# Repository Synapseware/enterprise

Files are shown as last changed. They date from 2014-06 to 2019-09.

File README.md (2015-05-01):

Enterprise
==========
The Enterprise is a project which adds sound and light effects to a small plastic model USS Enterprise from the original Star Trek TV show.  There are various pieces and parts to make this massively over complicated system work.  For me, this project is about learning better techniques for making circuit boards, programming embedded systems and generally wasting massive amounts of time.

# Project Structure
## /board
This is where the Eagle CAD files reside.  You should use Eagle v7 (or greater) to view/edit.

## /core
The heart of the system, driven by an Atmel ATMega328p micro controller clockec at 20MHz.  This is a hand built system and *does not run any Arduino firmware.*  The core is responsible for playing sound effects and coordinating light effects throughout the ship.

## /eeprom-test
A diagnostic firmware image for tracking down problems with the C++ conversion, hardware issues, etc, that are preventing the EEPROM chips from working correctly.

## /effects
The sound files used to generate the the EEPROM image file, and the latest binary EEPROM image file.  Plus lots of ther other sound effects.

## /entutil
Various programs written in C++ (tested only on Linux), mainly for converting 8bit 8KHz wave files to a standard EEPROM image file for uploading to the core.

## /lib
Shared code, drivers and other utilities extracte from the [libs](https://github.com/Synapseware/libs/libs.git) repository.

## /nacelle
A sub project within the main Enterprise project, the [Nacelle](https://github.com/Synapseware/enterprise/tree/master/nacelle) folder contains all the Atmel assembly language files for the nacelle lighting effects boards.

# Processing
## The core is responsible for:
* Sending new lighting effects to the Nacelle's for storage via EEPROM
* Sound?
* Some lighting effects
* USB interface

## Unsupported functionality:
* Processing battery level
* Uploading new firmware to subordinate processors

## Hardware System Composition
* Main CPU board
  * Main CPU
  * core lighting effects support
  * sound effects & speaker driver
* Power & USB board
  * USB to COM port
  * charging LiPo battery
  * 5V boost/regulator
* Nacelle boards (2 total)
  * nacelle lighting effects

The power & USB board provides communications for the system via a USB to virtual COM port driver chip, as well as a 5V boost/regulator for powering the CPU's.  The board has 6 outputs, 2 for serial RX & TX, USB power, 5V boost, raw battery line and ground.  The connector is meant to mate to the main board so that the main board can receive power and communications lines without the risk of a highly complicated system board.

The main CPU board has a single ATMega328P micro-controller (uC) which drives the sound effects, core lighting effects and is able to communicate with the nacelle driver boards via I2C.

### Board Details

	Power Board pinout (facing up, pins down, L-R)
	1 - RX
	2 - TX
	3 - VBUS
	4 - VBATT
	5 - VBOOST (5V)
	6 - GND

	Nacelle Board pinout (facing up, pins down, L-R)
	1 - MOSI/SDA
	2 - MISO
	3 - SCK/SCL
	4 - Pwr
	5 - GND
	6 = Reset

## Diagnostics
There are 4 LEDs on the main board located near the programming header.  In order from board edge in:
* Heartbeat
* Sound play back
* Serial transfers
* I2C transfers

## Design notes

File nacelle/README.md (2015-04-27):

Nacelle
=======
Nacelle lighting effects for the Enterprise project.

Platform:	ATTiny2313
Source:		AVR assembly

***Built using AVRA!***

## Theory
The Nacelle "driver" is an ATTiny2313 clocked at 20MHz.  It is configured to push data over a serial interface to a pair of chained ST16CP05 LED driver chips.  This was chosen over the original Charlie-plexed design for wiring simplicity.

The Nacelle driver board is designed to communicate with the Enterprise core board via an I2C interface.  The core will send effects commands to the driver boards at various times to change the speed, direction, brightness, etc, of the nacelle animations.

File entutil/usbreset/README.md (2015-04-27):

USB Reset
=========

1) Compile the program:
    
    $ make

2) Get the Bus and Device ID of the USB device you want to reset:

    $ lsusb  
*Output:*
    Bus 002 Device 003: ID 0fe9:9010 DVICO  

3) Make our compiled program executable:

    $ chmod +x usbreset

4) Execute the program with sudo privilege
    - make necessary substitution for <Bus> and <Device> ids as found by running the lsusb command:

    $ sudo ./usbreset /dev/bus/usb/002/003

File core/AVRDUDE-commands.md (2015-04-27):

AVRDUDE commands
================
For interacting with the Enterprise main board.

# Upload & Fuses

### programming
	avrdude -c usbtiny -p m328p -B 1 -U flash:w:.\release\enterprise.hex

### reading fuses
	avrdude -c usbtiny -p m328p -B 8 -U hfuse:r:.\high.txt:h -U lfuse:r:.\low.txt:h -U efuse:r:.\ext.txt:h

### writing fuses
*(external crystal)*
	avrdude -c usbtiny -p m328p -B 8 -U lfuse:w:0xff:m -U hfuse:w:0xdf:m -U efuse:w:0xff:m

*(internal 8mHz r/c)*
	avrdude -c usbtiny -p m328p -B 8 -U lfuse:w:0xe2:m -U hfuse:w:0xdf:m -U efuse:w:0xff:m

## Build tool test...
echo avrdude -c usbtiny -p $(avrdevice) -B 8 -U flash:w:"$(OutputDirectory)\$(MSBuildProjectName).hex" > upload.bat

avrdude -c usbtiny -p usb162 -U hfuse:r:.\high.txt:h -U lfuse:r:.\low.txt:h -U efuse:r:.\ext.txt:h
avrdude -c usbtiny -p usb162 -U lfuse:w:0xde:m -U hfuse:w:0xd9:m -U efuse:w:0xf7:m
avrdude -c usbtiny -p usb162 -U lfuse:w:0xde:m -U hfuse:w:0xd1:m -U efuse:w:0xf4:m

avrdude -c usbtiny -p usb162 -U lfuse:w:0xff:m
avrdude -c usbtiny -p usb162 -U hfuse:w:0xd1:m
avrdude -c usbtiny -p usb162 -U efuse:w:0xf4:m

## i2c/twi execution notes:
	@ 400kHz (1/4x10+6 = 2.5x10-6), it takes 2.5uS to transfer a single bit. 2.5x10-6 x 8 = 20uS per byte.  The AVR core @ 20MHz can theoretically execute 2x10+8/second or 1 instruction every 50x10-12 (50nS) seconds.  20uS is 200 times slower, so 200 instructions for every i2c byte transfer.
    It's well worth it to have the I2C interface be interrupt driven.

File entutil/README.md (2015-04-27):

Enterprise Utility Programs
===========================

## stitch
Stitch's together a series of raw audio files and generates the proper output bin file.  Stitch should operate on files that were created by the 'scvt' utility.

### Help info
	stitch - EEPROM sound effects utility builder for the Enterprise
	   combines a set of wav files into a single output file suitable for programming to the EEPROM on the Enterprise board.

	stitch -o {outputfile} -p {pagesize} {input file 1...n}
	   -o  Output file name.
	   -p  Page size.  This must reflect the page size of the target hardware.  256 bytes is the required size for the AT24C1024 chip.
	   {input files}  Give a list of pre-processed WAV files.  Preprocessing is done by the scvt (Sound Convert) utility.

## scvt
Converts a single .wav file (RIFF WAVE format) file to the raw Enterprise EEPROM format, which is simply the audio data from the input wave file.  Files must be 8bit, mono, below 22kHz sample rate.  Ideally files will be 8kHz.  The extracted audio is always saved to a new file with an extension of "snd".

### Examples

	scvt spock-bridge.wav

Takes the "spock-bridge.wav" file, verifies that it contains only 8 bit mono sound data with an 8kHz sampling rate then extracts just the audio chunk and saves it to a new file named "spock-bridge.snd" file in the same directory as the input file.  Any existing file will be over written.

### Help info

	scvt {input file}
	   Converts a standard wave file to the intermediary Enterprise format.

## upload
Uploads an effects EEPROM image to the Enterprise.  Default speed is 57600.

### Examples:

	upload -p /dev/ttyACM0 -i {image-file}
	upload -b 9600 -p /dev/ttyACM0 -i {image-file}

### Saving settings:
To save the current port and BAUD rate, specify the -s flag.

### Help info
	upload -i {filename} -p {serial port} -b {baud rate} -s
	Uploads an EEPROM effects file to the Enterprise.
	  -i  The EEPROM image file to upload to the Enterprise.
	  -b  Specify the baud rate to use.  Must be a standard value (e.g. 9600, 57600, etc).
	  -p  Specify the serial port to use.
	         List serial ports with 'll /dev/tty*' at the command prompt.
	  -s  Save the given port and baud rate as the new defaults.
	         Note: settings are saved in the .upload-settings file in the current directory.

## hdrinfo
View information about an EEPROM image by examining the first 256 bytes of the file.

	hdrinfo {image-file}

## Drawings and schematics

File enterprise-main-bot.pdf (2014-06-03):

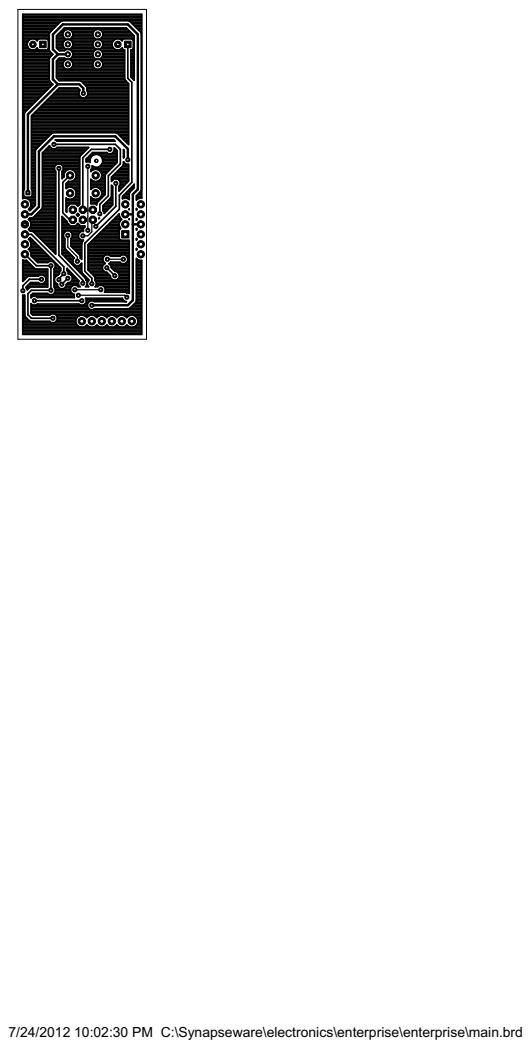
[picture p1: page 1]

7/24/2012 10:02:30 PM C:\Synapseware\electronics\enterprise\enterprise\main.brd

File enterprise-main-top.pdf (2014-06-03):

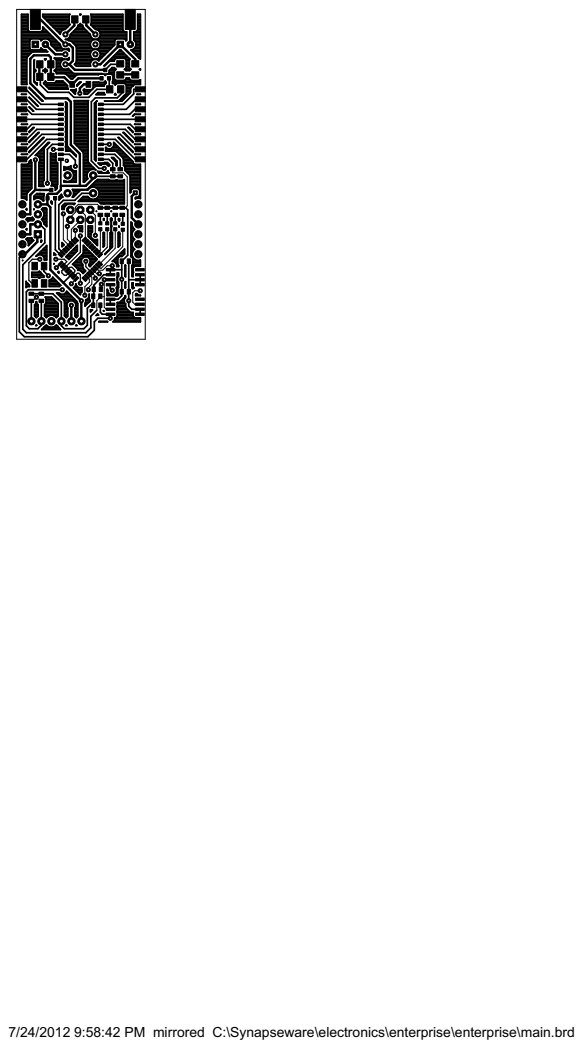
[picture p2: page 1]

7/24/2012 9:58:42 PM mirrored C:\Synapseware\electronics\enterprise\enterprise\main.brd

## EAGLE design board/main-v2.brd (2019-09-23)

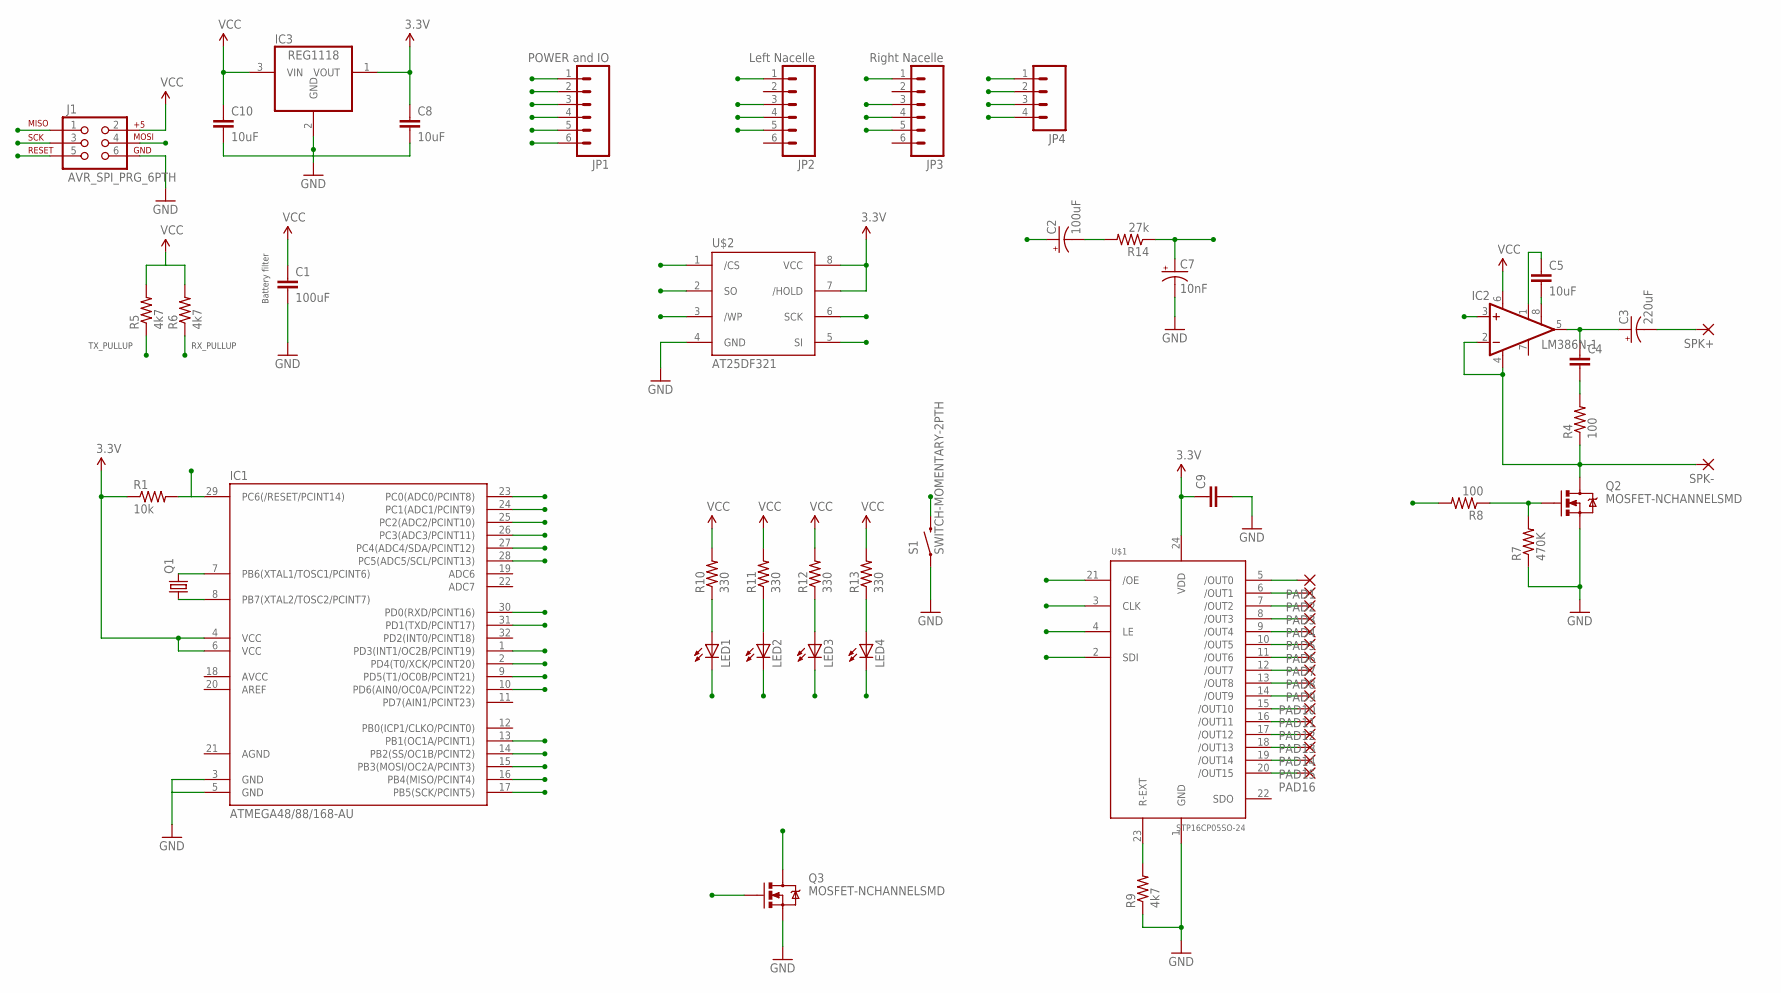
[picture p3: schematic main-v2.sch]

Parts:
C1: 100uF; CTZ3
C2: 100uF; CPOL-RADIAL-10UF-25V
C3: 220uF; CPOL-RADIAL-10UF-25V
C4: CAP1206; 1206
C5: 10uF; 1206
C7: 10nF; CPOL-RADIAL-10UF-25V
C8, C10: 10uF; CTZ3
C9: CAP0805; 0805
IC1: ATMEGA48/88/168-AU; TQFP32-08
IC2: LM386N-1; DIL08
IC3: REG1118; SOT223
J1: AVR_SPI_PRG_6PTH; 2X3
JP1: POWER and IO; 1X06
JP2: Left Nacelle; 1X06
JP3: Right Nacelle; 1X06
JP4: M04PTH; 1X04
LED1, LED2, LED3, LED4: LED0603; LED-0603
PAD1, PAD2, PAD3, PAD4, PAD5, PAD6, PAD7, PAD8, PAD9, PAD10, PAD11, PAD12, PAD13, PAD14, PAD15, PAD16: SMD2; SMD1,27-2,54
Q1: CRYSTALCTS406; CTS406
Q2, Q3: MOSFET-NCHANNELSMD; SOT23-3
R1: 10k; 0805
R4, R8: 100; 1206
R5, R6, R9: 4k7; 0805
R7: 470K; 1206
R10, R11, R12, R13: 330; 0805
R14: 27k; 1206
S1: SWITCH-MOMENTARY-2PTH; TACTILE-PTH
SPK+: SMD5; SMD2,54-5,08
SPK-: SMD5; SMD2,54-5,08
U$1: STP16CP05SO-24; SO-24
U$2: AT25DF321; WSOIC-8

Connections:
3.3V: C8.+ (1), C9.1, IC1.4 (VCC), IC1.6 (VCC), IC3.1 (VOUT), R1.1, U$1.24 (VDD), U$2.7 (/HOLD), U$2.8 (VCC)
/OE: IC1.13 (PB1(OC1A/PCINT1)), U$1.21 (/OE)
/SS: IC1.14 (PB2(SS/OC1B/PCINT2)), U$1.4 (LE), U$2.1 (/CS)
AGND: IC1.21 (AGND)
AUDIO_PWR: IC1.2 (PD4(T0/XCK/PCINT20)), R8.2
FILTERED_PWM: C7.1 (+), IC2.3 (+IN), R14.1
GND: C1.- (2), C7.2 (-), C8.- (2), C9.2, C10.- (2), IC1.3 (GND), IC1.5 (GND), IC3.2 (GND), J1.6, JP1.6, JP4.4, Q2.2 (S), Q3.2 (S), R7.1, R9.1, S1.1, U$1.1 (GND), U$2.4 (GND)
LED1: IC1.23 (PC0(ADC0/PCINT8)), LED1.C
LED2: IC1.24 (PC1(ADC1/PCINT9)), LED2.C
LED3: IC1.25 (PC2(ADC2/PCINT10)), LED3.C
LED4: IC1.26 (PC3(ADC3/PCINT11)), LED4.C
MISO: IC1.16 (PB4(MISO/PCINT4)), J1.1, U$2.2 (SO)
MOSI: IC1.15 (PB3(MOSI/OC2A/PCINT3)), J1.4, U$1.2 (SDI), U$2.5 (SI)
unnamed: IC1.8 (PB7(XTAL2/TOSC2/PCINT7)), Q1.1
unnamed: IC1.7 (PB6(XTAL1/TOSC1/PCINT6)), Q1.3 (2)
unnamed: C3.1 (+), C4.1, IC2.5 (OUT)
unnamed: C5.1, IC2.1 (GAIN)
unnamed: C4.2, R4.2
unnamed: C5.2, IC2.8 (GAIN)
unnamed: Q2.1 (G), R7.2, R8.1
unnamed: IC2.2 (-IN), IC2.4 (GND), Q2.3 (D), R4.1, SPK-.1
unnamed: LED1.A, R10.1
unnamed: LED2.A, R11.1
unnamed: R9.2, U$1.23 (R-EXT)
unnamed: LED3.A, R12.1
unnamed: LED4.A, R13.1
unnamed: PAD1.1, U$1.5 (/OUT0)
unnamed: PAD2.1, U$1.6 (/OUT1)
unnamed: PAD3.1, U$1.7 (/OUT2)
unnamed: PAD4.1, U$1.8 (/OUT3)
unnamed: PAD5.1, U$1.9 (/OUT4)
unnamed: PAD6.1, U$1.10 (/OUT5)
unnamed: PAD7.1, U$1.11 (/OUT6)
unnamed: PAD8.1, U$1.12 (/OUT7)
unnamed: PAD9.1, U$1.13 (/OUT8)
unnamed: PAD10.1, U$1.14 (/OUT9)
unnamed: PAD11.1, U$1.15 (/OUT10)
unnamed: PAD12.1, U$1.16 (/OUT11)
unnamed: PAD13.1, U$1.17 (/OUT12)
unnamed: PAD14.1, U$1.18 (/OUT13)
unnamed: PAD15.1, U$1.19 (/OUT14)
unnamed: PAD16.1, U$1.20 (/OUT15)
unnamed: C2.2 (-), R14.2
NCL_GND: JP2.5, JP3.5, Q3.3 (D)
NCL_PWR: IC1.9 (PD5(T1/OC0B/PCINT21)), Q3.1 (G)
PWM_AUDIO: C2.1 (+), IC1.1 (PD3(INT1/OC2B/PCINT19))
PWR_SW: IC1.10 (PD6(AIN0/OC0A/PCINT22)), S1.3 (2)
RESET: IC1.29 (PC6(/RESET/PCINT14)), J1.5, R1.2
RX: IC1.30 (PD0(RXD/PCINT16)), JP1.2, R6.1
SCK: IC1.17 (PB5(SCK/PCINT5)), J1.3, U$1.3 (CLK), U$2.6 (SCK)
SCL: IC1.28 (PC5(ADC5/SCL/PCINT13)), JP2.3, JP3.3, JP4.2
SDA: IC1.27 (PC4(ADC4/SDA/PCINT12)), JP2.1, JP3.1, JP4.1
SPK+: C3.2 (-), SPK+.1
TX: IC1.31 (PD1(TXD/PCINT17)), JP1.1, R5.1
VBATT: C1.+ (1), JP1.5, JP2.4, JP3.4, JP4.3
VBUS: JP1.3
VCC: JP1.4, R5.2, R6.2, R10.2, R11.2, R12.2, R13.2
VCC+5V: C10.+ (1), IC2.6 (VS), IC3.3 (VIN), J1.2

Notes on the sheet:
TX_PULLUP
RX_PULLUP
Battery filter

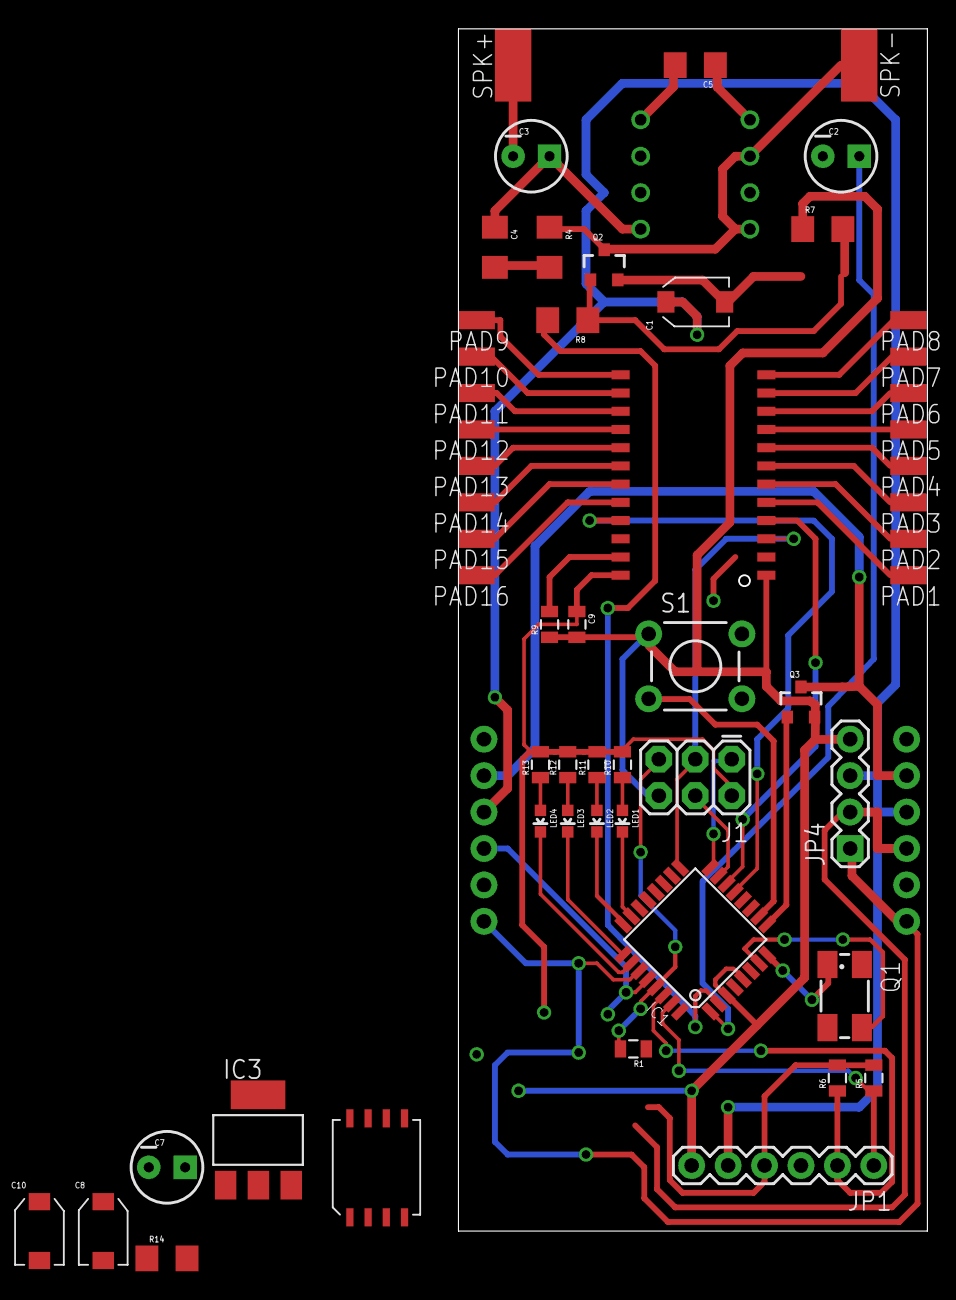
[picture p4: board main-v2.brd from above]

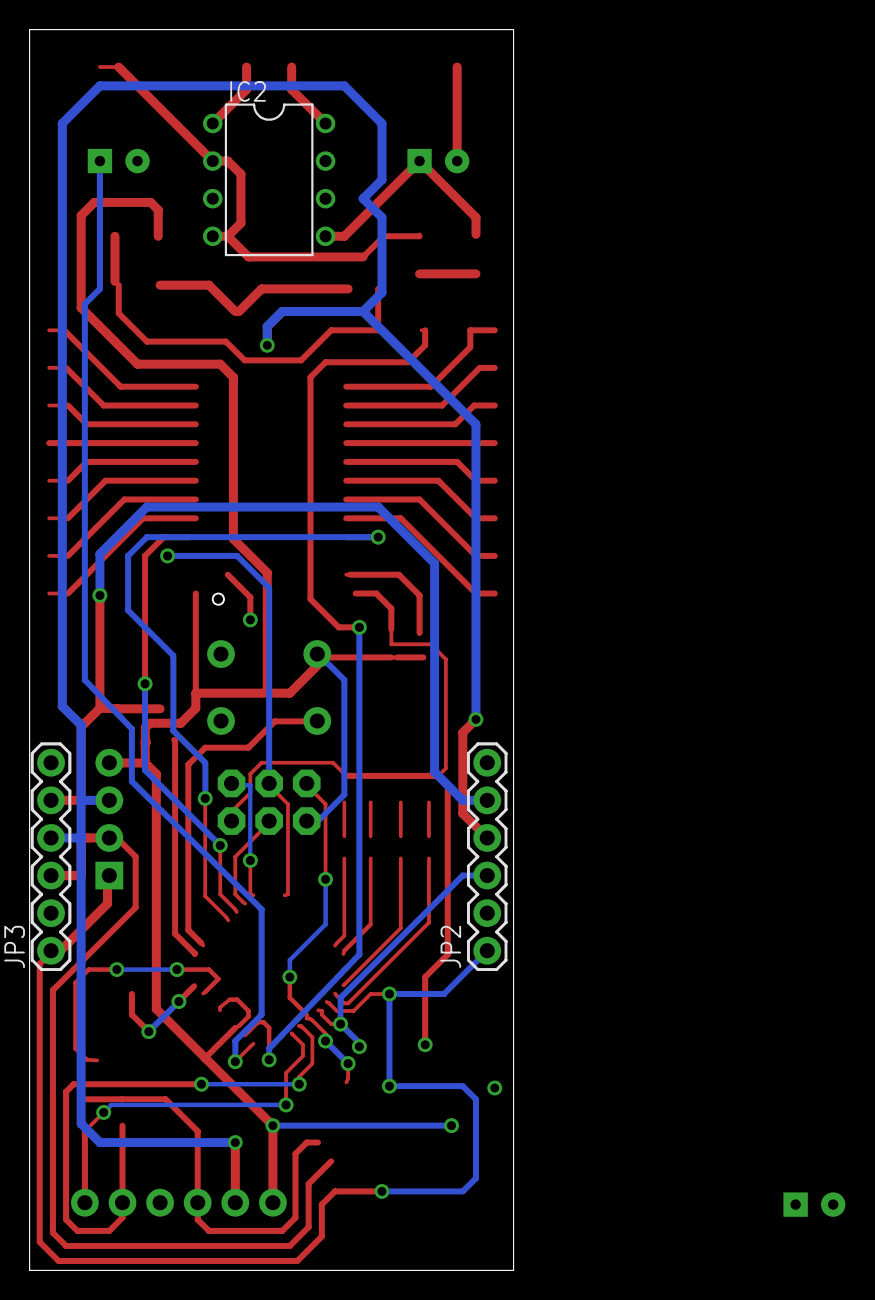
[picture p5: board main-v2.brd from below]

Board: 2 copper layers, 32.7 x 83.8 mm, 57 parts (3 on the bottom side), 56 nets.

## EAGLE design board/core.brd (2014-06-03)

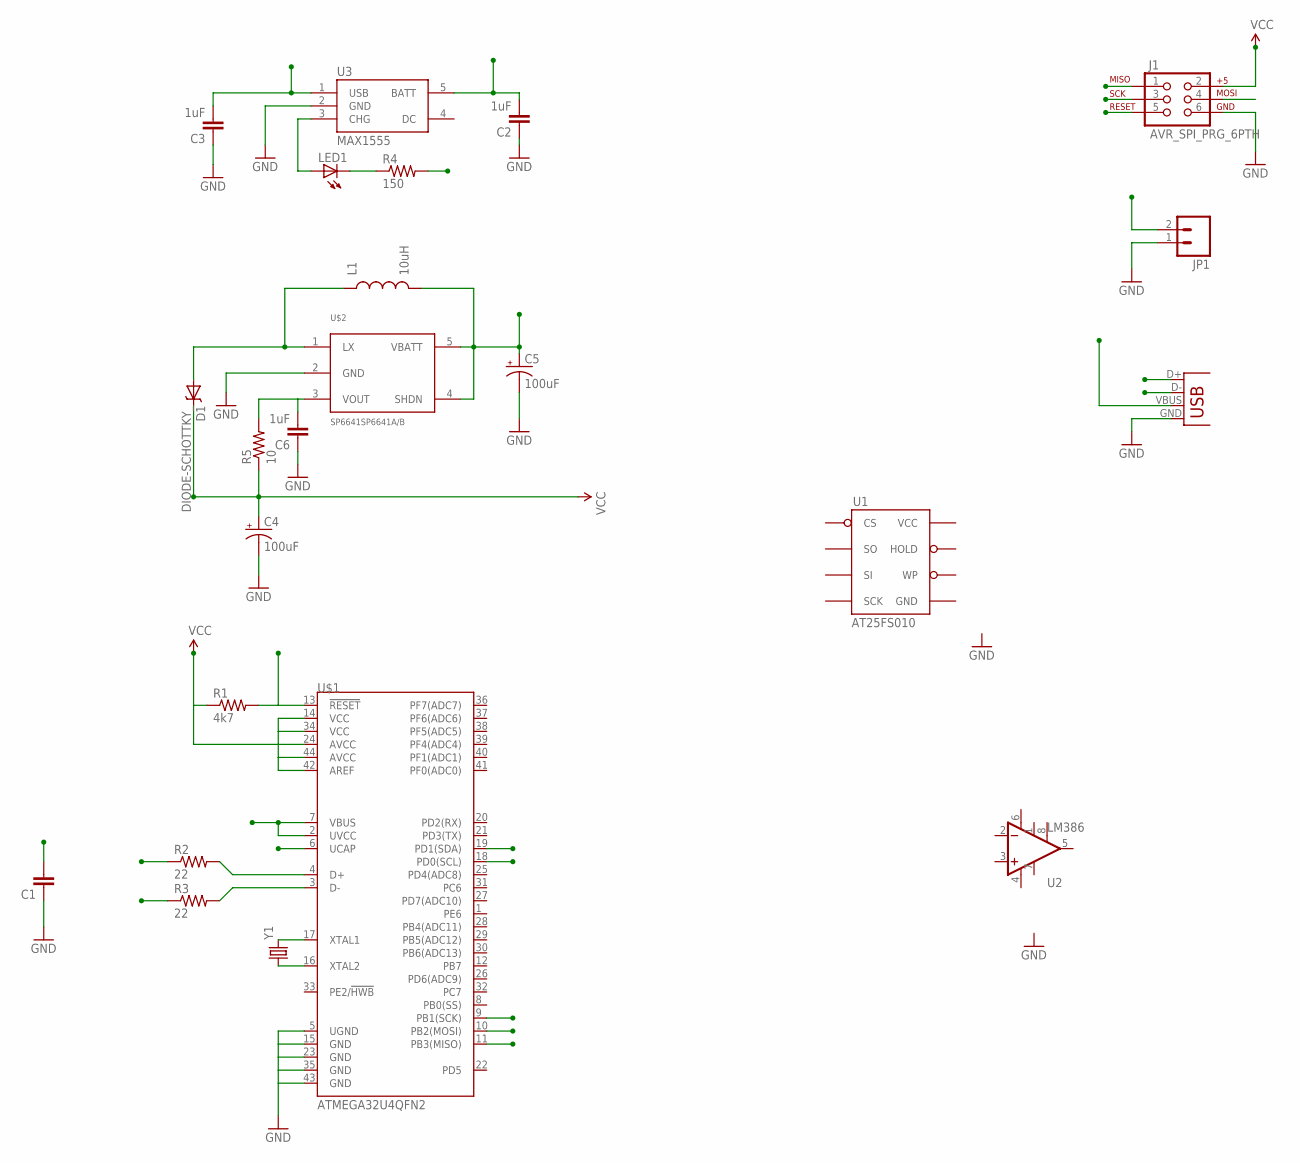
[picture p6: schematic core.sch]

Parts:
C1: CAP1206; 1206
C2, C3: 1uF; 1206
C4, C5: 100uF; PANASONIC_E
C6: 1uF; 0603-CAP
D1: DIODE-SCHOTTKY_; SMA-DIODE
J1: AVR_SPI_PRG_6PTH; 2X3
JP1: M02-JST-2MM-SMT; JST-2-SMD
L1: 10uH; CR75
LED1: LED0603; LED-0603
R1: 4k7; 0603-RES
R2, R3: 22; 0603-RES
R4: 150; 0603-RES
R5: 10; 0603-RES
U1: AT25FS010; SO08WIDE
U2: LM386; DIP08
U3: MAX1555; SOT23-5
U$1: ATMEGA32U4QFN2; QFN-44-NOPAD
U$2: SP6641SP6641A/B; SOT23-5
X1: USBSMD; USB-MINIB
Y1: CRYSTAL5X3; CRYSTAL-SMD-5X3

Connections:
/RESET: J1.5, R1.2, U$1.13 (!RESET)
GND: C1.1, C2.1, C3.1, C4.-, C5.-, C6.1, J1.6, JP1.1 (2), U3.2 (GND), U$1.5 (UGND), U$1.15 (GND), U$1.23 (GND), U$1.35 (GND), U$1.43 (GND), U$2.2 (GND), X1.GND
MISO: J1.1, U$1.11 (PB3(MISO))
MOSI: J1.4, U$1.10 (PB2(MOSI))
unnamed: R3.2, U$1.3 (D-)
unnamed: R2.2, U$1.4 (D+)
unnamed: LED1.A, U3.3 (CHG)
unnamed: LED1.C, R4.1
unnamed: D1.A, L1.P$1 (1), U$2.1 (LX)
unnamed: U$1.17 (XTAL1), Y1.3 (2)
unnamed: U$1.16 (XTAL2), Y1.1
unnamed: C6.2, R5.2, U$2.3 (VOUT)
SCK: J1.3, U$1.9 (PB1(SCK))
SCL: U$1.18 (PD0(SCL))
SDA: U$1.19 (PD1(SDA))
UCAP: C1.2, U$1.6 (UCAP)
USB_D+: R2.1, X1.D+
USB_D-: R3.1, X1.D-
V+: U2.6 (V+)
V-: U2.4 (V-)
VBATT: C2.2, C5.+, JP1.2 (1), L1.P$2 (2), U3.5 (BATT), U$2.4 (SHDN), U$2.5 (VBATT)
VBUS: C3.2, R4.2, U3.1 (USB), U$1.2 (UVCC), U$1.7 (VBUS), X1.VBUS
VCC: C4.+, D1.C, J1.2, R1.1, R5.1, U$1.14 (VCC), U$1.24 (AVCC), U$1.34 (VCC), U$1.42 (AREF), U$1.44 (AVCC)

Board: 2 copper layers, 23 parts (0 on the bottom side), 19 nets, no tracks yet.

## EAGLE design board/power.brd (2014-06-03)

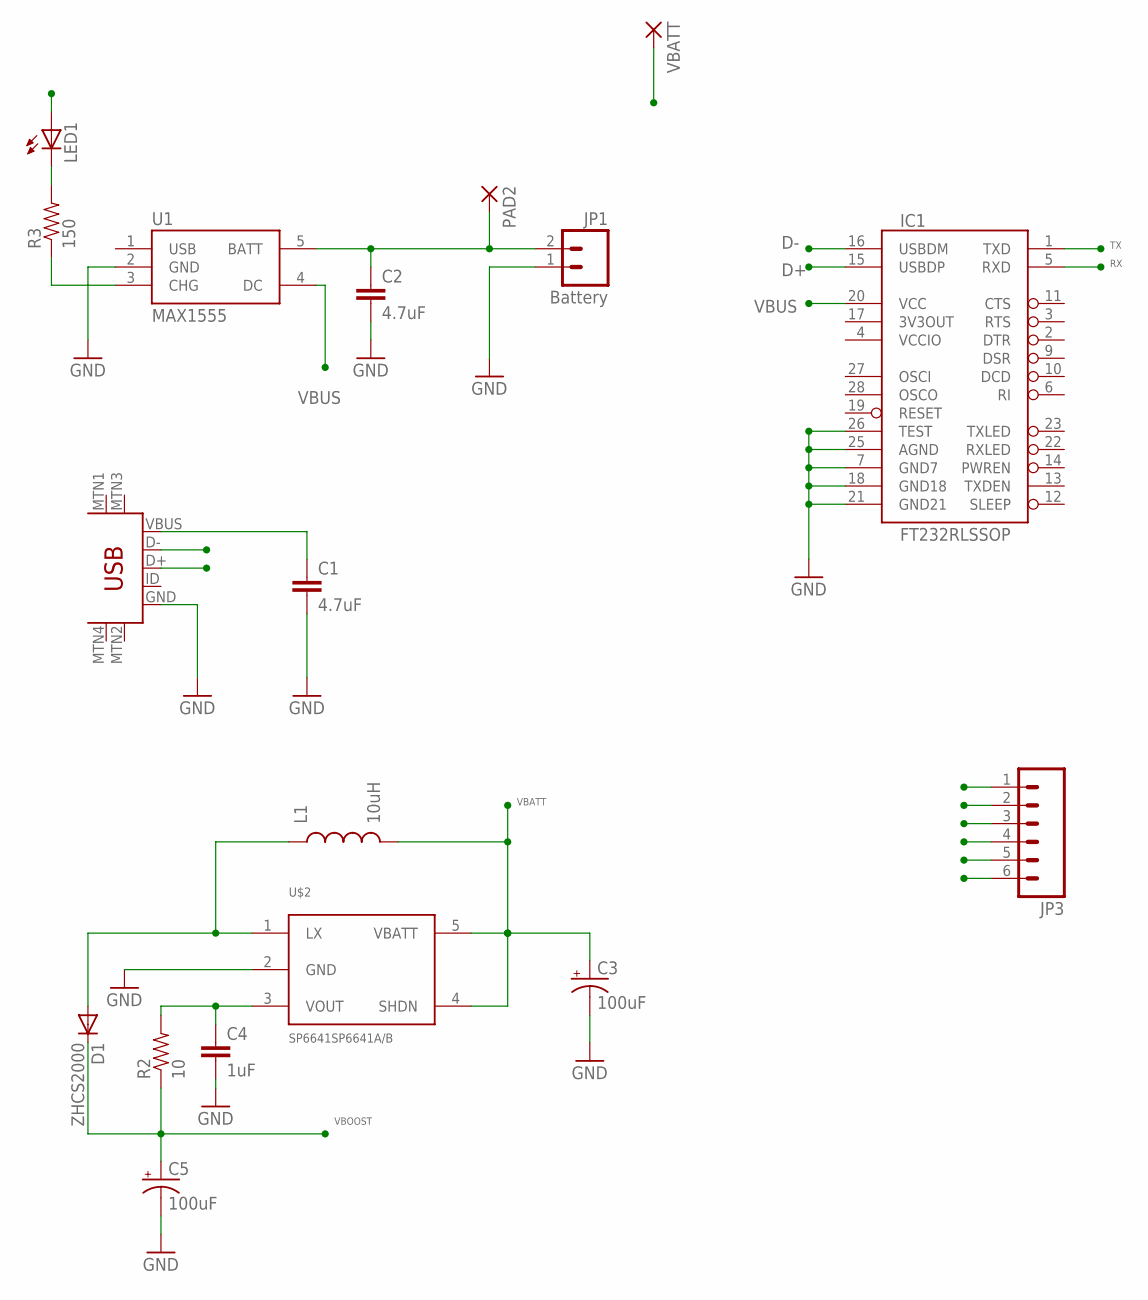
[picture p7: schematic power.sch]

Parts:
C1, C2: 4.7uF; 1206
C3, C5: 100uF; PANASONIC_D
C4: 1uF; 0805
D1: ZHCS2000; SMB-DIODE
IC1: FT232RLSSOP; SSOP28DB
JP1: Battery; JST-2-SMD
JP3: M06SMD; 1X06-SMD
L1: 10uH; CR54
LED1: LED0603; LED-0603
PAD2: WIREPAD2,54/1,0; 2,54/1,0
R2: 10; 0603-RES
R3: 150; 0603-RES
U1: MAX1555; SOT23-5
U$1: USB-MINIB-5PIN; USB-MINIB
U$2: SP6641SP6641A/B; SOT23-5
VBATT: WIREPAD2,54/1,0; 2,54/1,0

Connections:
D+: IC1.15 (USBDP), U$1.D+
D-: IC1.16 (USBDM), U$1.D-
GND: C1.2, C2.2, C3.-, C4.2, C5.-, IC1.7 (GND7), IC1.18 (GND18), IC1.21 (GND21), IC1.25 (AGND), IC1.26 (TEST), JP1.1, JP3.6, U1.2 (GND), U$1.GND, U$2.2 (GND)
LX: D1.A, L1.P$1 (1), U$2.1 (LX)
unnamed: LED1.C, R3.2
unnamed: R3.1, U1.3 (CHG)
unnamed: C2.1, JP1.2, PAD2.1, U1.5 (BATT)
RX: IC1.5 (RXD), JP3.1
TX: IC1.1 (TXD), JP3.2
VBATT: C3.+, JP3.5, L1.P$2 (2), U$2.4 (SHDN), U$2.5 (VBATT), VBATT.1
VBOOST: C5.+, D1.C, JP3.4, R2.1
VBUS: C1.1, IC1.20 (VCC), JP3.3, LED1.A, U1.4 (DC), U$1.VBUS
VCCIO: IC1.4 (VCCIO)
VOUT: C4.1, R2.2, U$2.3 (VOUT)

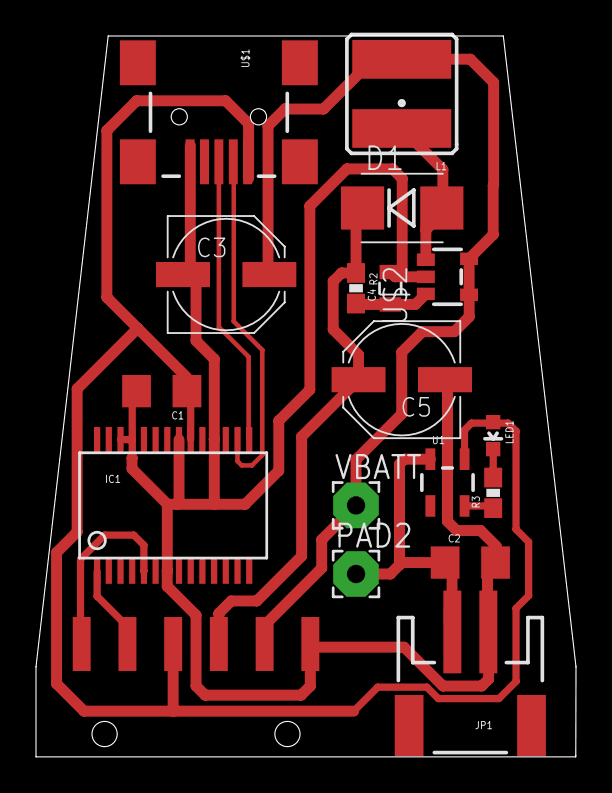
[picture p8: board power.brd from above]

Board: 2 copper layers, 30.0 x 40.0 mm, 18 parts (0 on the bottom side), 13 nets.

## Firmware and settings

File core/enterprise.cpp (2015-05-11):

#include "enterprise.h"



// Scratch buffer
char scratch[128];


// UART RX ring buffer
char uart_buffer[UART_RX_BUFFER];
RingBuffer uart_rx_buff(uart_buffer, UART_RX_BUFFER / sizeof(char));


// declare enterprise globals
Uart				uart(&uart_rx_buff);
Events				events(MAX_EVENT_RECORDS);
Sermem				sermem(&uart, scratch, sizeof(scratch) / sizeof(char));


// - - - - - - - - - - - - - - - - - - - - - - - - - - - - - - - - - - - - - - - - - - -
// enables the button after a timeout
static uint8_t _wakingUp = 0;
static void enableButton(eventState_t state)
{

	_wakingUp = 0;
}

// - - - - - - - - - - - - - - - - - - - - - - - - - - - - - - - - - - - - - - - - - - -
// checks the state of the button
static void checkButton(eventState_t state)
{
	// ignore any button presses after waking up
	if (_wakingUp)
		return;

	// check switch pin
	if ((SWITCH_PINS & (1<<SWITCH_PIN)) != 0)
	{
		// enable switch interrupt
		SWITCH_PCMSK |= (1<<SWITCH_PCINT);
		return;
	}

	//TODO: Button debounce

	// shutdown the CPU and all effects
	efx_off();

	// shutoff the LEDs
	dbg_led_off();
	serial_led_off();
	play_led_off();
	twi_led_off();

	// enable button interrupt which will wake us back up
	SWITCH_PCMSK |= (1<<SWITCH_PCINT);
	_wakingUp = 1;

	switch_en();

	// go to sleep
	sleep_cpu();

	//
	events.registerOneShot(enableButton, 8000, EVENT_STATE_NONE);

	// wake back up
	efx_on();
}

// - - - - - - - - - - - - - - - - - - - - - - - - - - - - - - - - - - - - - - - - - - -
// processes a communications request from the serial port
static void processCommRequest(void)
{
	int data = uart.read();
	if (-1 == data)
		return;

	// shutoff effects while processing request
	efx_off();

	switch (data & 0x5F)
	{
		case 'V':
			uart.write_P(PSTR("\r\nVersion: 0.5\r\n"));
			break;
		default:
			// process the request
			sermem.process(data);
			break;
	}

	efx_on();
}

// - - - - - - - - - - - - - - - - - - - - - - - - - - - - - - - - - - - - - - - - - - -
// Initialize the Effects system
void initEffects(void)
{
	// initialize effects
	uart.write_P(PSTR("Initializing effects header\r\n"));
	int samples = efx_init(&events);
	int len = sprintf_P(scratch, PSTR("  Found %d samples on the EEPROM\r\n"), samples);
	uart.write(scratch, len);
}

// - - - - - - - - - - - - - - - - - - - - - - - - - - - - - - - - - - - - - - - - - - -
// Initialize the hardware
void init(void)
{
	dbg_led_en();
	serial_led_en();
	play_led_en();
	twi_led_en();

	dbg_led_off();
	serial_led_off();
	play_led_off();
	twi_led_off();

	// - - - - - - - - - - - - - - - - - - - - - - - - - - - - - - - - - - - - - - - - - - -
	// establish event timer & handler
	// timer1, event timer
	// Set CTC mode (Clear Timer on Compare Match) (p.133)
	// Have to set OCR1A *before anything else*, otherwise it gets reset to 0!
	PRR		&=	~(1<<PRTIM1);
	OCR1A	=	(F_CPU / SAMPLE_RATE);
	TCCR1A	=	0;
	TCCR1B	=	(1<<WGM12) |	// CTC
				(1<<CS10);
	TIMSK1	=	(1<<OCIE1A);

	events.setTimeBase(SAMPLE_RATE);

	// setup sleep mode
	set_sleep_mode(SLEEP_MODE_PWR_DOWN);
	sleep_enable();

	// setup switch input
	SWITCH_DDR		&= ~(1<<SWITCH_PIN);
	SWITCH_PINS		|= (1<<SWITCH_PIN);
	SWITCH_PCMSK	|= (1<<SWITCH_PCINT);
	PCICR			|= (1<<SWITCH_PCICR);

	events.registerHighPriorityEvent(fadeStatusLed, 0, EVENT_STATE_NONE);
	events.registerEvent(readNextStatusVal, 700, EVENT_STATE_NONE);

	// enable all interrupts
	sei();
}

// - - - - - - - - - - - - - - - - - - - - - - - - - - - - - - - - - - - - - - - - - - -
// main program loop
int main()
{
	init();

	uart.write_P(PSTR("Enterprise main board booting up.\r\n"));
	sermem.showHelp();

	initEffects();

	efx_on();
	efx_startSample(SFX_EFX_OPENING);

	while(1)
	{
		// process any pending events
		events.doEvents();

		// process any communications data
		processCommRequest();
	}
}

// - - - - - - - - - - - - - - - - - - - - - - - - - - - - - - - - - - - - - - - - - - -  - -
// Should be running @ 8.000kHz - this is the event sync driver method
ISR(TIMER1_COMPA_vect)
{
	// play audio data
	efx_renderAudioData();

	// trigger event cycle
	events.sync();
}

// - - - - - - - - - - - - - - - - - - - - - - - - - - - - - - - - - - - - - - - - - - -
// Fires when the user presses the button
ISR(SWITCH_PCVECT)
{
	if (_wakingUp)
		return;
	
	// disable pin change interrupt
	SWITCH_PCMSK &= ~(1<<SWITCH_PCINT);

	// require user to press button for at least 1/8 second
	events.registerOneShot(checkButton, 1000, EVENT_STATE_NONE);
}

// - - - - - - - - - - - - - - - - - - - - - - - - - - - - - - - - - - - - - - - - - - -
// receive buffer interrupt vector
ISR(USART_RX_vect)
{
	showSerialStatus();

	char data = UDR0;
	uart.receiveHandler(data);
}

// - - - - - - - - - - - - - - - - - - - - - - - - - - - - - - - - - - - - - - - - - - -
// transmit interrupt vector
ISR(USART_TX_vect)
{
	showSerialStatus();

	uart.transmitHandler();
}

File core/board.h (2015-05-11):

/*
 * board.h
 *
 * Created: 11/29/2011 8:27:26 PM
 *  Author: Matthew
 */ 


#ifndef BOARD_H_
#define BOARD_H_


//----------------------------------------------------------------------------------------------
// Buttons
#define SWITCH_DDR			DDRD
#define SWITCH_PIN			PORTD6
#define SWITCH_PINS			PIND
#define SWITCH_PORT			PORTD
#define SWITCH_PCINT		PCINT22
#define SWITCH_PCMSK		PCMSK2
#define SWITCH_PCICR		PCIE2
#define SWITCH_PCVECT		PCINT2_vect
#define switch_en()			SWITCH_DDR |= (1<<SWITCH_PIN)


//----------------------------------------------------------------------------------------------
// LED1 - TWI constants and LED
//#define TWI_LED_DDR			DDRC
//#define TWI_LED_PORT		PORTC
//#define TWI_LED_PIN			PORTC0

#define twi_led_en()		TWI_LED_DDR |= (1<<TWI_LED_PIN)
#define twi_led_on()		TWI_LED_PORT &= ~(1<<TWI_LED_PIN)
#define twi_led_off()		TWI_LED_PORT |= (1<<TWI_LED_PIN)


//----------------------------------------------------------------------------------------------
// LED2 - Play LED
#define LED_PLAY_PORT		PORTC
#define LED_PLAY_DDR		DDRC
#define LED_PLAY_PIN		PORTC1

#define play_led_en()		LED_PLAY_DDR |= (1<<LED_PLAY_PIN)
#define play_led_on()		LED_PLAY_PORT &= ~(1<<LED_PLAY_PIN)
#define play_led_off()		LED_PLAY_PORT |= (1<<LED_PLAY_PIN)


//----------------------------------------------------------------------------------------------
// LED3 - Serial LED
#define SERIAL_LED_PORT		PORTC
#define SERIAL_LED_DDR		DDRC
#define SERIAL_LED_PIN		PORTC2

#define serial_led_en()		SERIAL_LED_DDR |= (1<<SERIAL_LED_PIN)
#define serial_led_on()		SERIAL_LED_PORT &= ~(1<<SERIAL_LED_PIN)
#define serial_led_off()	SERIAL_LED_PORT |= (1<<SERIAL_LED_PIN)


//----------------------------------------------------------------------------------------------
// LED4 - Debug LED
#define LED_DBG_PORT		PORTC
#define LED_DBG_DDR			DDRC
#define LED_DBG_LINE		PORTC3

#define dbg_led_en()		LED_DBG_DDR |= (1<<LED_DBG_LINE)
#define dbg_led_on()		LED_DBG_PORT &= ~(1<<LED_DBG_LINE)
#define dbg_led_off()		LED_DBG_PORT |= (1<<LED_DBG_LINE)


//----------------------------------------------------------------------------------------------
// Audio out
#define AUDIO_DDR			DDRD
#define AUDIO_PORT			PORTD
#define AUDIO_OUT_PIN		PORTD3

#define audioOut_en()		AUDIO_DDR |= (1<<AUDIO_OUT_PIN)


//----------------------------------------------------------------------------------------------
// Audio amp power
#define AMPPWR_DDR			DDRD
#define AMPPWR_PORT			PORTD
#define AMPPWR_OUT_PIN		PORTD4

#define ampPwr_off()		AMPPWR_PORT &= ~(1<<AMPPWR_OUT_PIN)
#define ampPwr_on()			AMPPWR_PORT |= (1<<AMPPWR_OUT_PIN)
#define ampPwr_en()			AMPPWR_DDR |= (1<<AMPPWR_OUT_PIN)


//----------------------------------------------------------------------------------------------
// Nacelle power
#define NCL_DDR				DDRD
#define NCL_PORT			PORTD
#define NCL_PIN				PORTD5

#define nacellePower_off()	NCL_PORT |= (1<<NCL_PIN)
#define nacellePower_on()	NCL_PORT &= ~(1<<NCL_PIN)
#define nacellePower_en()	NCL_DDR |= (1<<NCL_PIN)


//----------------------------------------------------------------------------------------------
// STP16CP05
#define STP_OE				PORTB1
#define STP_CLK				PORTB5
#define STP_LE				PORTB2
#define STP_SDI				PORTB4






#endif /* BOARD_H_ */

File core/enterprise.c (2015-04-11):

#include "enterprise.h"


volatile uint8_t _idx = 0;
volatile uint8_t _val = 0;
void fadeStatusLed(eventState_t state)
{
	if (_idx == 0)
		dbg_led_on();
	if (_idx >= _val)
		dbg_led_off();
	_idx += 4;
}

volatile uint8_t _i = 0;
void readNextStatusVal(eventState_t state)
{
	_val = pgm_read_byte(&SLEEPY_EYES[_i++]);
	if (_i >= SLEEPY_EYES_LEN)
		_i = 0;
}


// - - - - - - - - - - - - - - - - - - - - - - - - - - - - - - - - - - - - - - - - - - -
// uart receive callback method
//	gets called by the UART/USART when a byte of data has been received
volatile char _rxData = 0;
volatile char _dataReceived = 0;
void receiveCallback(char data)
{
	_rxData = data;
	_dataReceived = 0xff;
}

// - - - - - - - - - - - - - - - - - - - - - - - - - - - - - - - - - - - - - - - - - - -
// processes a communications request from the serial port
void processCommRequest()
{
	if (!_dataReceived)
		return;

	uartEndReceive();

	sfx_off();

	_dataReceived = 0;
	spie_process(_rxData);
	switch (_rxData & 0x5F)
	{
		case 'V':
			uart_putstrM(PSTR("\r\nVersion: 0.5\r\n"));
			break;
	}

	sfx_on();

	// setup the UART receive interrupt handler
	uartBeginReceive(&receiveCallback);
}

// - - - - - - - - - - - - - - - - - - - - - - - - - - - - - - - - - - - - - - - - - - -
// enables the button after a timeout
volatile uint8_t _wakingUp = 0;
void enableButton(eventState_t state)
{
	_wakingUp = 0;
}

// - - - - - - - - - - - - - - - - - - - - - - - - - - - - - - - - - - - - - - - - - - -
// checks the state of the button
void checkButton(eventState_t state)
{
	// ignore any button presses after waking up
	if (_wakingUp)
		return;

	// check switch pin
	if ((SWITCH_PINS & (1<<SWITCH_PIN)) != 0)
	{
		// enable switch interrupt
		SWITCH_PCMSK |= (1<<SWITCH_PCINT);
		return;
	}

	//TODO: Button debounce

	// shutdown the CPU and all effects
	sfx_off();

	// shutoff the LEDs
	dbg_led_off();
	serial_led_off();
	play_led_off();
	twi_led_off();

	// enable button interrupt which will wake us back up
	SWITCH_PCMSK |= (1<<SWITCH_PCINT);
	_wakingUp = 1;

	switch_en();

	// go to sleep
	sleep_cpu();

	//
	registerOneShot(enableButton, 8000, EVENT_STATE_NONE);

	// wake back up
	sfx_on();
}

// - - - - - - - - - - - - - - - - - - - - - - - - - - - - - - - - - - - - - - - - - - -
void init(void)
{
	play_led_en();
	play_led_off();

	dbg_led_en();
	dbg_led_on();

	// initialize effects
	sfx_init();

	// initialize SPI EEPROM support
	spie_init();

	// initialize USART
	uart_init();

	// setup the UART receive interrupt handler
	uartBeginReceive(&receiveCallback);

	// - - - - - - - - - - - - - - - - - - - - - - - - - - - - - - - - - - - - - - - - - - -
	// establish event timer & handler
	// timer1, event timer
	// Set CTC mode (Clear Timer on Compare Match) (p.133)
	// Have to set OCR1A *before anything else*, otherwise it gets reset to 0!
	PRR		&=	~(1<<PRTIM1);
	OCR1A	=	(F_CPU / SAMPLE_RATE);
	TCCR1A	=	0;
	TCCR1B	=	(1<<WGM12) |	// CTC
				(1<<CS10);
	TIMSK1	=	(1<<OCIE1A);

	setTimeBase(SAMPLE_RATE);

	// setup sleep mode
	set_sleep_mode(SLEEP_MODE_PWR_DOWN);
	sleep_enable();

	// setup switch input
	SWITCH_DDR		&= ~(1<<SWITCH_PIN);
	SWITCH_PINS		|= (1<<SWITCH_PIN);
	SWITCH_PCMSK	|= (1<<SWITCH_PCINT);
	PCICR			|= (1<<SWITCH_PCICR);


	registerHighPriorityEvent(fadeStatusLed, 0, EVENT_STATE_NONE);
	registerEvent(readNextStatusVal, 500, EVENT_STATE_NONE);

	// enable all interrupts
	sei();
}

// - - - - - - - - - - - - - - - - - - - - - - - - - - - - - - - - - - - - - - - - - - -
// main program loop
int main()
{
	init();

	uart_putstrAM(PSTR("Enterprise main board booting up...\r\n"), 0);

	spie_showHelp();

	sfx_on();

	sfx_startSample(SFX_EFX_OPENING);

	while(1)
	{
		// process any pending events
		eventsDoEvents();

		// process any communications data
		processCommRequest();
	}
}

// - - - - - - - - - - - - - - - - - - - - - - - - - - - - - - - - - - - - - - - - - - -  - -
// Should be running @ 8.000kHz - this is the event sync driver method
ISR(TIMER1_COMPA_vect)
{
	// trigger event cycle
	eventSync();
}

// - - - - - - - - - - - - - - - - - - - - - - - - - - - - - - - - - - - - - - - - - - -
// Fires when the user presses the button
ISR(SWITCH_PCVECT)
{
	if (_wakingUp)
		return;
	
	// disable pin change interrupt
	SWITCH_PCMSK &= ~(1<<SWITCH_PCINT);

	// require user to press button for at least 1/8 second
	registerOneShot(checkButton, 1000, EVENT_STATE_NONE);
}

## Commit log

2014-06-03 Trying to get the make build chain to work...
2014-06-09 experimenting with new driver files
2014-06-09 Trying to make assembly build work
2014-06-11 Nacelle is now building via Assembly build but drivers are not yet converted.
2014-06-11 Updating nacelle build, working on stp16cp05 assembly driver
2014-06-24 Adding support for new driver files - converting from assembly to C++
2015-04-14 Fixing build issues from migration
    [effects.cpp, enterprise.cpp]
2015-04-14 Fixing uart compile error
    [enterprise.cpp]
2015-04-16 Raw copy of EnterpriseIO project
    A very rough WinForms app which is used to generate the firmware sound effects file.
    [motion-data.csv]
2015-04-21 Added analysis switch
2015-04-22 Working through lots of bugs with UART and Effects
    [effects.cpp, enterprise.cpp, sermem.cpp]
2015-04-22 Reworking the upload processing for the EEPROM
    [sermem.cpp]
2015-04-23 Changing event handling
    Changed event handling and function registration: Moved handlers out of disparete files into the main "Enterprise" file (the one with int main()). Hopefully this fixes some of the callback problems.
    [effects.cpp, enterprise.cpp, sermem.cpp]
2015-04-25 Fixing upload processing
    I think the EEPROM wiring is bad on the board... it's not working.
    [sermem.cpp]
2015-04-25 Updating event registrations and LED calls
2015-04-25 Removing old EnterpriseIO C# project
    [motion-data.csv]
2015-04-26 Working on fixes for the Enterprise
    [enterprise.cpp, sermem.cpp]
2015-04-27 Removing old files
    [power-new.brd, power-new.sch]
2015-04-28 Trying to fix upload
    * Experimenting with different BAUD rates. So far, 38400 seems to be the most reliable, but it used to transfer @ 115.2k. The board seems to have taken some damage from the move.
    * Transfer size function fixed and correctly reading data from host
    * Upload utility updated for new processing tree
    [sermem.cpp]
2015-05-01 Working on EEPROM test project and UART RingBuffer
2015-05-01 Fixed the TWI interface
    Seems there was a problem with the waiting for-i2c-logic. Fixed and now it's working. Yippie. SO MUCH WASTED TIME. Ugh.
    [main.brd, main.sch]
2015-05-01 Improving serial transfers and on-board LEDs
2015-05-01 Fixing up UART read's in sermem
    [enterprise.cpp, sermem.cpp, test.cpp]
2015-05-04 Fixing bugs with TWI code
    [board.h, effects.cpp, enterprise.cpp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]
2015-05-06 Sound playing - taking too long to load
    The sound data is playing, but taking far too long to load. Sound effects seem to be playing at 50% or less of their actual speed. Yuck.
    [effects.cpp, enterprise.cpp, sermem.cpp]
2015-05-08 Fixing load, read and startup
    [effects.cpp]
2015-05-08 Fixing LEDs header and implementation
2015-05-08 Fixing LEDs header and implementation
    Conflicts:
    core/leds.cpp
    core/leds.h
2015-05-11 Reverting changes from Effects class
    The Effects lib changes accidentally made it to master causing master to be broken. Branch is reverted to last-known good state and Enterprise is playing effects correctly.
    [effects.cpp]
2015-05-11 LEDs working and improved read times
2015-05-11 Improved read performance for async reads
    It's more efficient to wait after the start/ack/nack status changes then it is to process the next async step with a callback. This coupled with overclocking the TWI bus @ 800kHz has bought some brea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
2019-09-23 V2 board files(?)
    [main-v2.brd, main-v2.sch]

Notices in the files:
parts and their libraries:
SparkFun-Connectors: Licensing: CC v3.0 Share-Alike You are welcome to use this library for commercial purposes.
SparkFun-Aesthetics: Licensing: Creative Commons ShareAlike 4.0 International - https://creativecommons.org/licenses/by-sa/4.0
